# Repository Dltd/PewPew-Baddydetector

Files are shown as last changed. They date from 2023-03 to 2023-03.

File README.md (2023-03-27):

# Baddydetector
PoC for having actions of baddies in the virtual world, visible in the physical world.

v3:
The Raspberry Pi connects to a server on which multiple honeypots run.
The server listens on 8 ports and will monitor the log files of the honeypots for new attacks or automated scans and hacking attempts. 

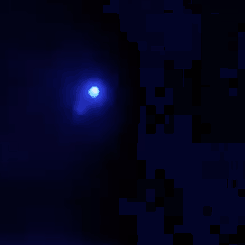
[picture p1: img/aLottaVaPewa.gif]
 

The logs are tailed and bound to one of the ports. One log is monitored twice, where the second time it is filtered on a keyword.
When the keyword is detected, it reflects input being entered in a shell on one of the honeypots. The connected LED only blinks when a bot or person actually does something in the pot.

When an activity takes place on the selected honeypots, the server will send a '1' to the client, the RPi.

When the client receives the data, it will blink two LEDs which are connected to the GPIO pin per port. 8 GPIO's are used to blink the 16 leds. 

The honeypot configuration will be deciding in if 'innocent' traffic will also be registered and blink a LED or not.
As this is not yet the final version of the idea I have, that will be for later to further tweak and tune or improve somehow.

The LEDs are put in a specific order which I liked, like so:
```bash
2	3	4	5	6	7	8
1						1
8	7	6	5	4	3	2
```

Initially I only needed to see v1 work but sometimes you just get carried away, so there you go.

For more details, consult the different versions:

[PoC_v3](/PoC_v3)

[PoC_v2](/PoC_v2)

[PoC_v1](/PoC_v1)

For the LEDs I added two test scripts to run and check if you have any dead LEDs.
You can find them [here](/Other_scripts/)

# PoC v3
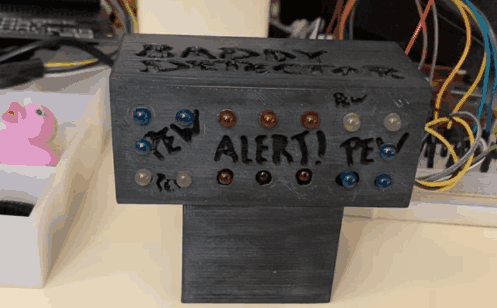
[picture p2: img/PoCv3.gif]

  
# PoC v2
name

# PoC v1
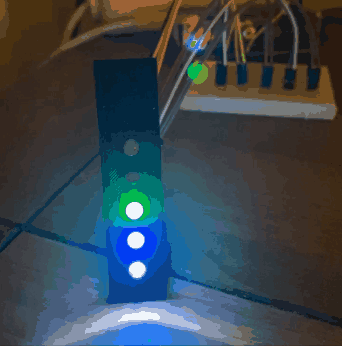
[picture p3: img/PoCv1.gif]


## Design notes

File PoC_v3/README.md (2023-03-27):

# Baddydetector
PoC for having actions of baddies in the virtual world, visible in the physical world.

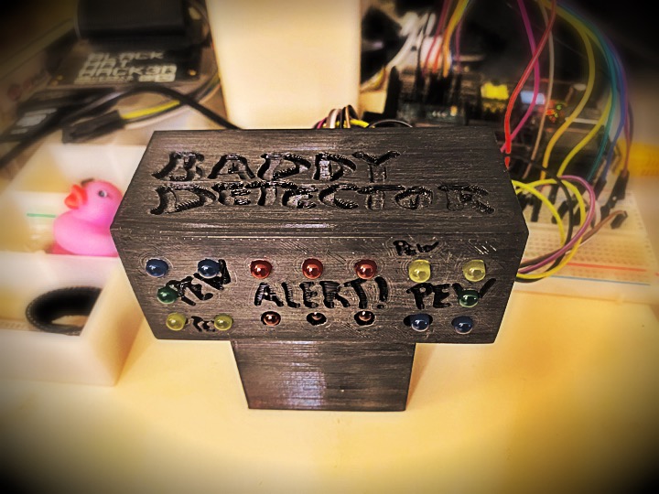
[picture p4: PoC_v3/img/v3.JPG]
Version 3


# Pics
[some of the 3D stuff](https://github.com/Dltd/PewPew-Baddydetector/blob/main/PoC_v3/README.md#3d-stuff)

[Mess is fun!](https://github.com/Dltd/PewPew-Baddydetector/blob/main/PoC_v3/README.md#some-mess)

[Soldering and wiring](https://github.com/Dltd/PewPew-Baddydetector/blob/main/PoC_v3/README.md#soldering-and-wiring)

# v3
The Raspberry Pi connects to a server on which multiple honeypots run.
The server listens on 8 ports and will monitor log files of 8 honeypots for new attacks or automated scans and hacking attempts. 

The logs are tailed and bound to one of the ports. One log is monitored twice, where the second time it is filtered on a keyword.
When the keyword is detected, it reflects input being entered in a shell on one of the honeypots. The connected LED only blinks when a bot or person actually does something in the pot.

When an activity takes place on the selected honeypots, the server will send a '1' to the client, the RPi.

When the client receives the data, it will blink two LEDs which are connected to the GPIO pin per port. 8 GPIO's are used to blink the 16 leds. 

The honeypot configuration will be decisive if 'innocent' traffic will also be registered and blink a LED or not.
As this is not yet the final version of the idea I have, that will be for later to further tweak and tune or improve somehow.

The LEDs are put in a specific order which I liked, like so:
```bash
2	3	4	5	6	7	8
1						1
8	7	6	5	4	3	2
```

Initially I only needed to see v1 work but sometimes you just get carried away, so there you go.

For more details, consult the different versions:

[PoC_v3](/PoC_v3)

[PoC_v2](/PoC_v2)

[PoC_v1](/PoC_v1)

For the LEDs I added two test scripts to run and check if you have any dead LEDs.
You can find them [here](/Other_scripts/)

# Some details of the build

The stl file used to print it [can be found here](/PoC_v3/PewPewBaddyDetectorV3.stl)

note: The LED holes might need manual adjustment to make them fit properly.
The design is for 5mm LED's.

You can edit it yourself on TinkerCAD [here](https://www.tinkercad.com/things/2NkG0boZJYC)

The server script runs on a Linux server that runs a collection of honeypots, [TPOT-CE](https://github.com/telekom-security/tpotce).
The /data directory contains the logs of the different honeypots, I selected a few popular pots to use for my idea.
These ports are only open for the IP from where the client connects from.
The idea is for a similar but larger project and it needed this PoC to get it going.

I wanted to create a physical dashboard that would notify me when there was an attack taking place on one of the honeypots.
Since this does not require a lot of power, I decided to use a Raspberry Pi 1 that I had lying around.

The RPi as a client will connect to specified ports on the server running the server script.
I designed and printed a LED holder that could stand on my desk and wired the LEDS to the RPi.

I have done some undocumented tests with a RPi Zero W but the functionality is limited due to the lack of real threading.
This can be simulated and runs sort of near real time but I haven't had time to further explore it yet.

# v3 model
https://youtu.be/B9omcdxjBJs



# PoC v3

v3BaddyDetector (https://www.youtube.com/watch?v=B9omcdxjBJsQ)

[Server](/PoC_v3/v3_pewserver.v3.1.py)

[Client](/PoC_v3/v3_pewclient.v3.py)

To make it more useful and easier to maintain, the v2 functionality was converted to python.

# PewClient and PewServer

Two Python scripts, pewclient.py and pewserver.py are designed to work together to monitor log files and visually indicate new attacks using LEDs on a Raspberry Pi.

# PewClient

The pewclient.py script runs on a Raspberry Pi 1 that I had lying around, collection dust. It is responsible for connecting to the pewserver.py script. Upon receiving signals from the server, it blinks the corresponding LED to indicate new attacks taking plsce. The script automatically reconnects to the server if the connection is lost and can be gracefully terminated by typing exit in the console. 

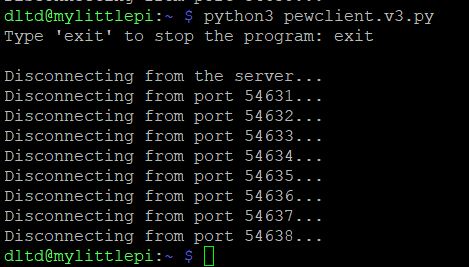
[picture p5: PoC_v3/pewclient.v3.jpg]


# PewServer

The pewserver.py script is a server that listens on multiple ports, each corresponding to a specific log file. When a client (like pewclient.py) connects to one of the ports, the server tails the associated log file in real-time. For each new line detected in the log, the server sends a signal to the connected client.

For one log, the data is filtered to reflect current activitiy by a bot or baddie in a shell in one of the honeypots.

When the client disconnects, the server gracefully handles the disconnection and continues listening for new connections.

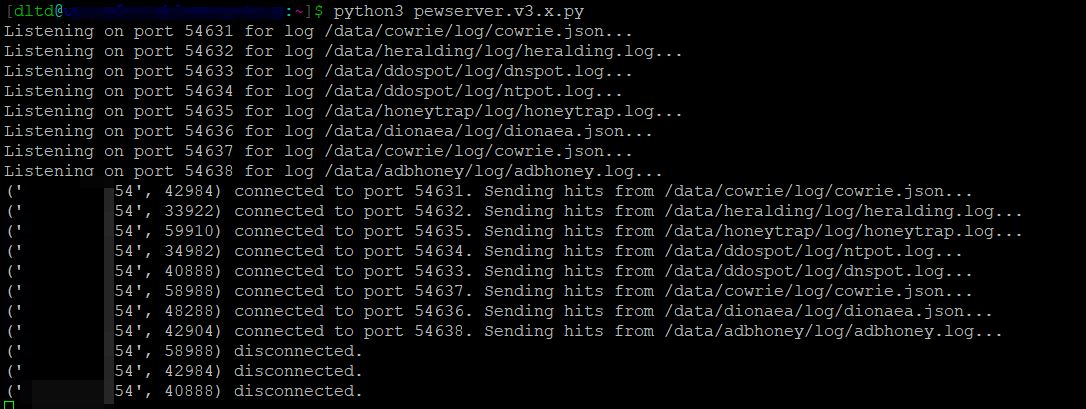
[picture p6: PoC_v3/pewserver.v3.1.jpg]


# Setup

Clone the repository:
```bash
git clone https://github.com/Dltd/PewPew-Baddydetector.git
```

Update the IP address and port numbers in both pewclient.py and pewserver.py to match your configuration.

Make sure the required dependencies are installed on the RPi and the server running the server script:

RPi:
```bash
pip install gpiozero aioconsole asyncio
```
Server:
```bash
pip install asyncio aiofiles
```

# Running the PoC

Run the pewserver.py script on the machine where the log files are located:
```bash
python3 pewserver.py
```

Run the pewclient.py script on the Raspberry Pi connected to the LEDs:
```bash
python3 pewclient.py
```

# Usage
When the pewclient.py script is running and connected to the pewserver.py script, it will blink the LEDs according to the incoming signals from the server. Each LED corresponds to a specific log file, and blinks whenever there is a new entry in that log file.

To gracefully stop the pewclient.py script, type exit in the console.

The LEDs are wired in pairs, in my PoC I used this configuration to make it more fun.

```
2	3	4	5	6	7	8

1						1

8	7	6	5	4	3	2
```

#  3D stuff

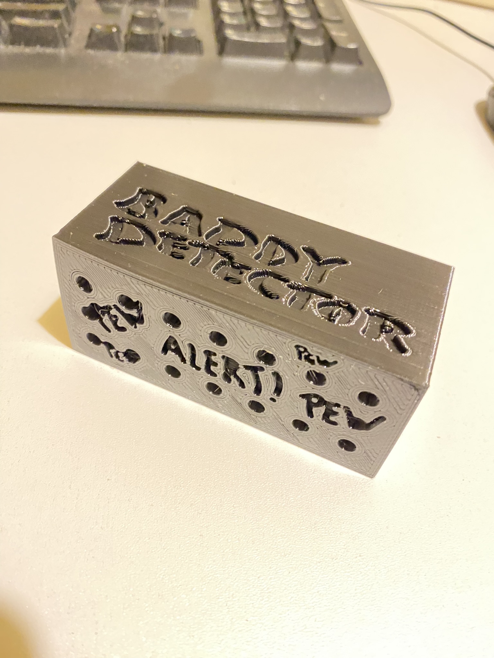
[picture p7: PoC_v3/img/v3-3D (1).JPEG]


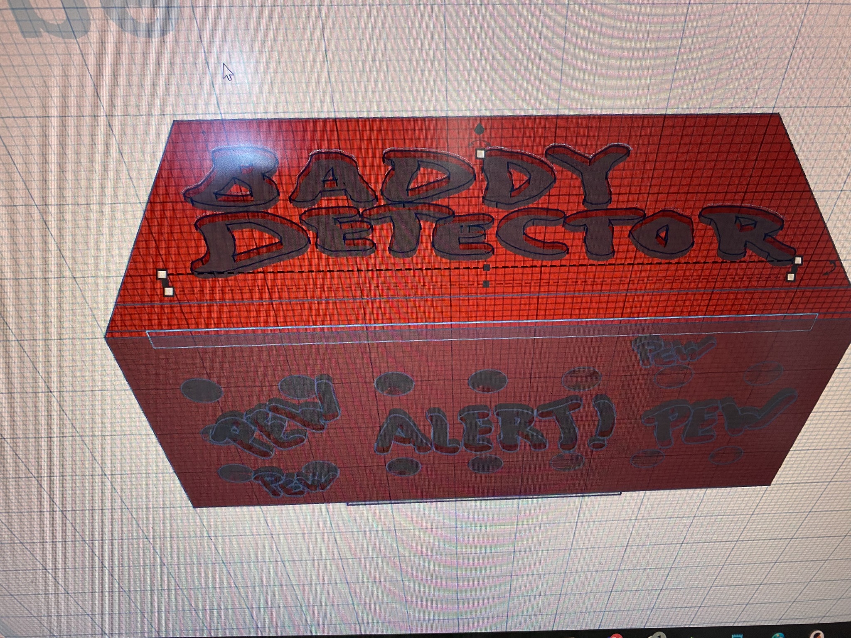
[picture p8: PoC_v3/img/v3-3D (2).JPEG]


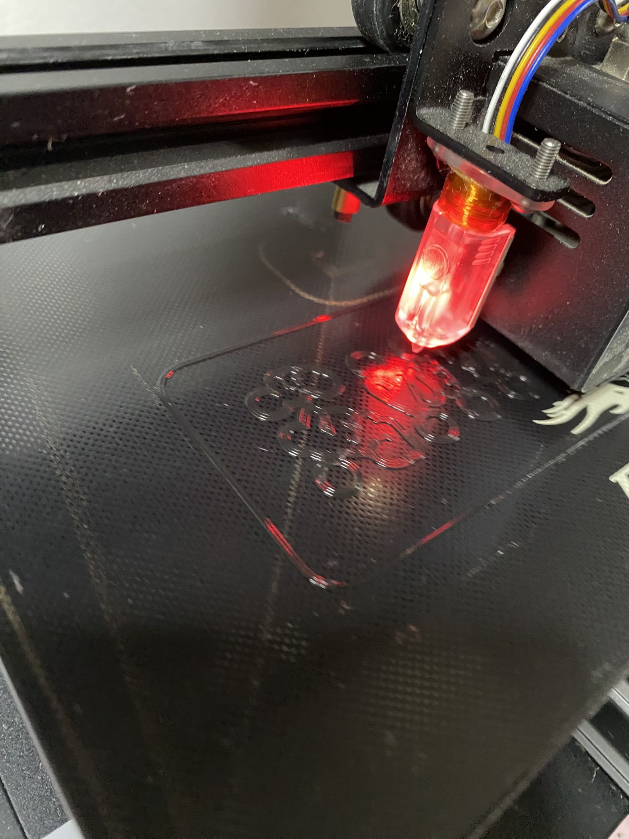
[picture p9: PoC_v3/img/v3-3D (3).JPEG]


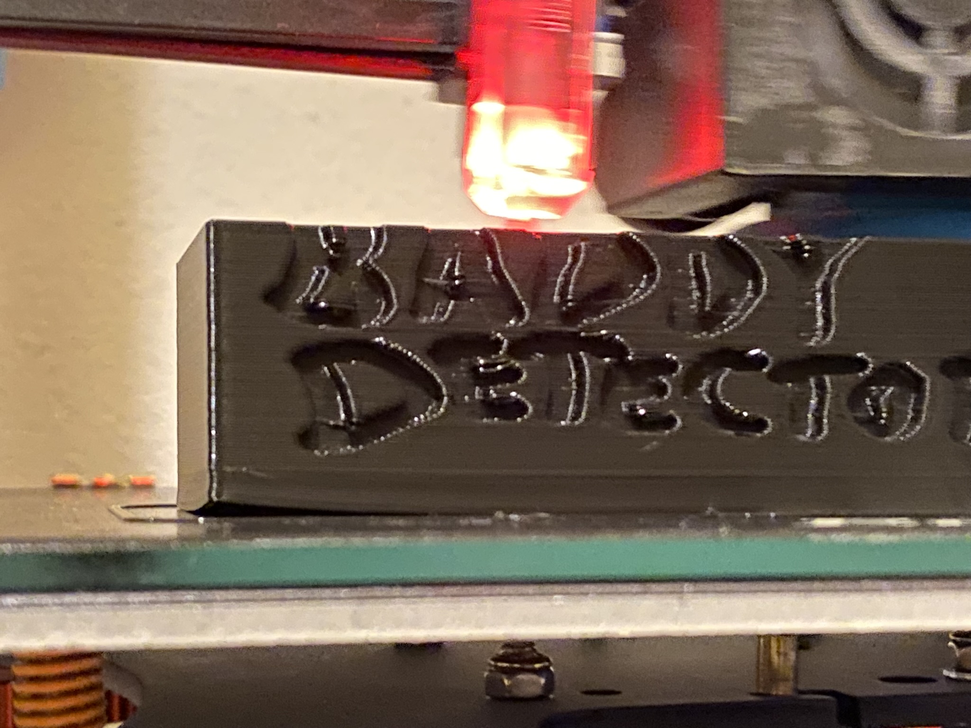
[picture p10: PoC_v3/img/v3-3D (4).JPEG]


# Some mess
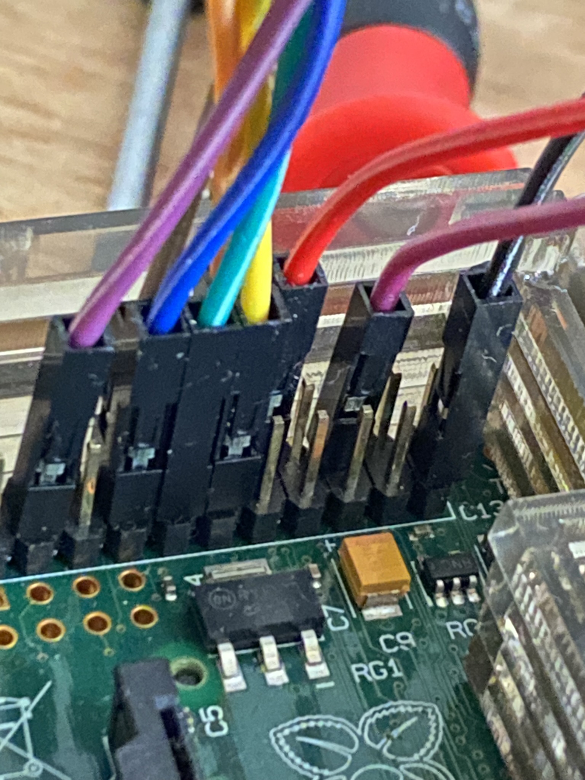
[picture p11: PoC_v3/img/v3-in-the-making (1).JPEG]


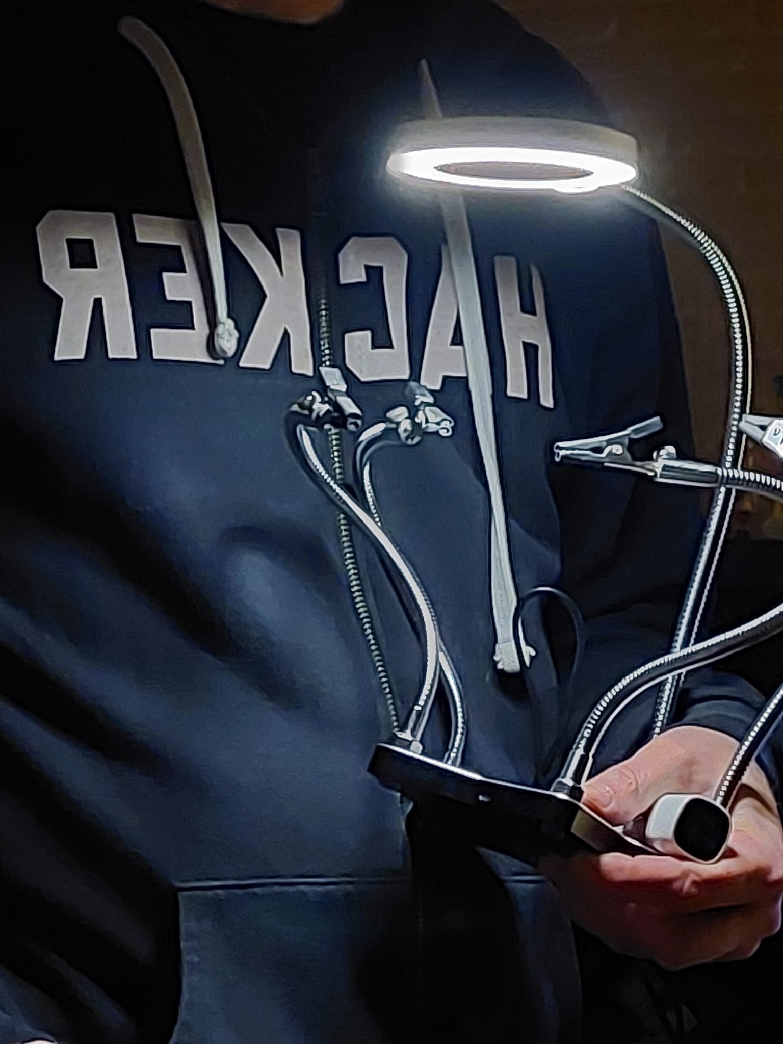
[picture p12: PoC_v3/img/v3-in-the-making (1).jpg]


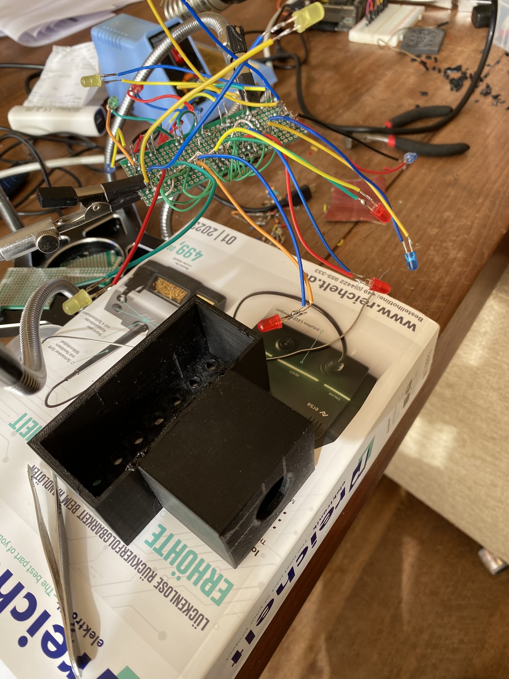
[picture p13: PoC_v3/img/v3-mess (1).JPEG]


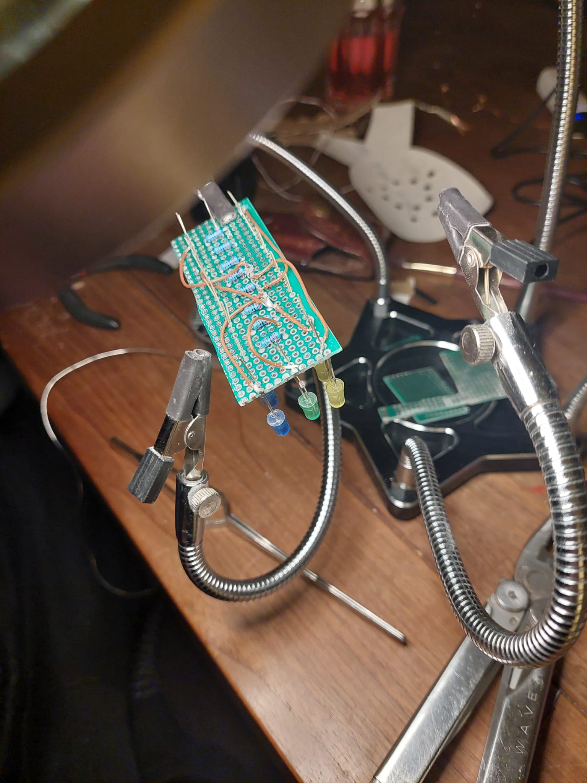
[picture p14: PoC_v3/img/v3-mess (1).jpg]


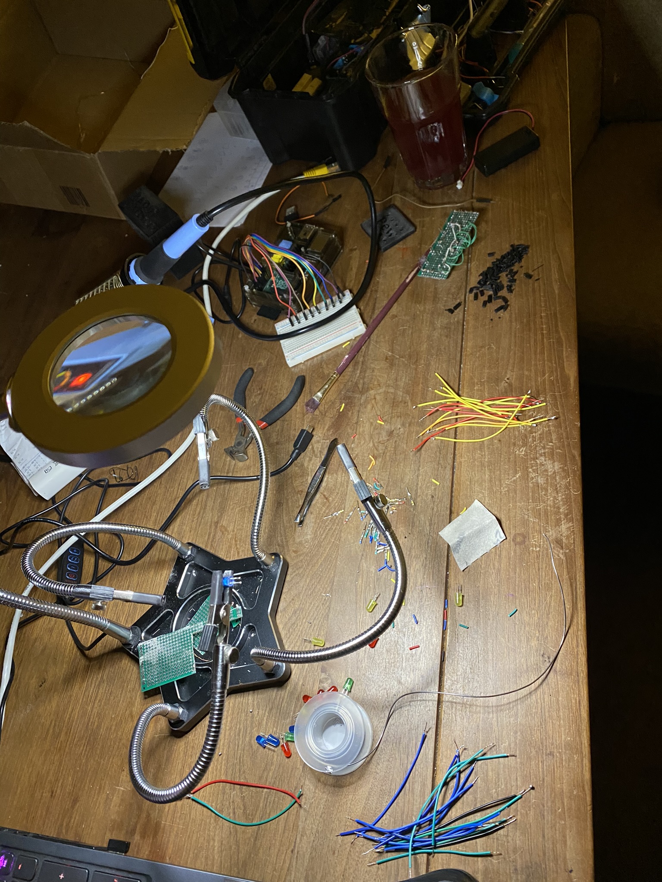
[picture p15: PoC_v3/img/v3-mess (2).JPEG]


# Soldering and wiring

Initially I had the LEDs soldered to a prototyping board.

The print I made and the base holding the print required some tweaking and tuning but since it was "just" for a PoC I didn't give it the extra bit of TLC it needed to make it fit properly. Also, the board was just a little too big to have space left to get the leds into the holes. 

So, I used a soldering iron to melt away some of the excess filament of the "neck" of the base but that did not improve that challenge all that much. ALso the center bottom three leds cannot be pushed in deep enough.

After soldering them all on the board, I cut them loose again and soldered wires on to the leds to have a little bit more freedom of movement within the casing.

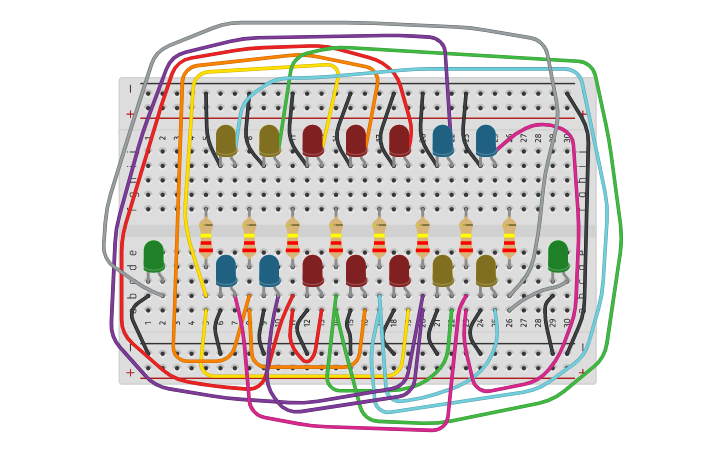
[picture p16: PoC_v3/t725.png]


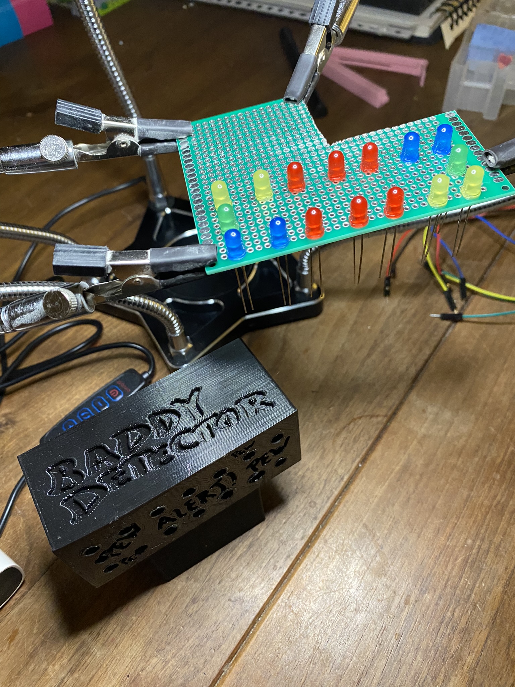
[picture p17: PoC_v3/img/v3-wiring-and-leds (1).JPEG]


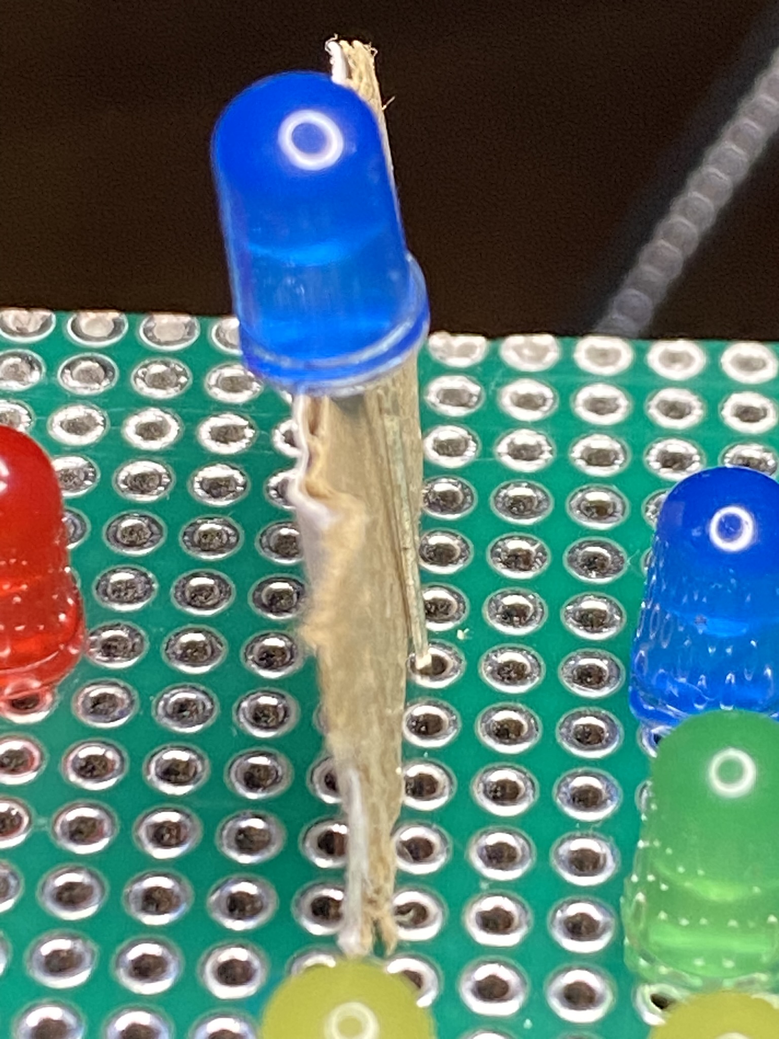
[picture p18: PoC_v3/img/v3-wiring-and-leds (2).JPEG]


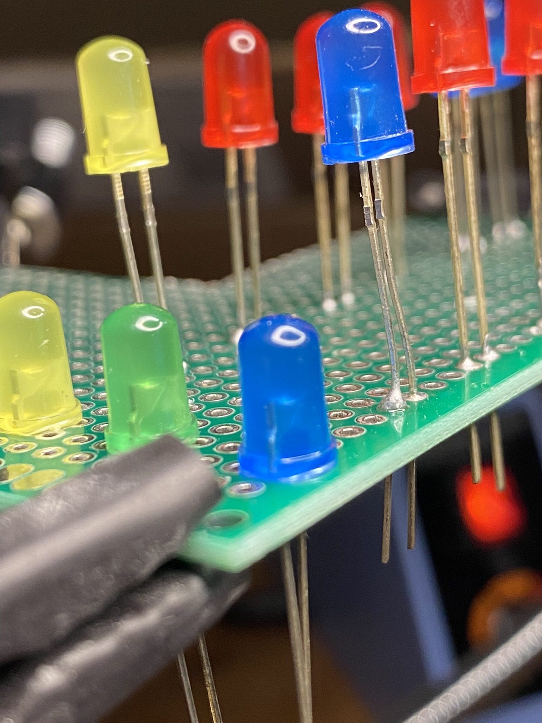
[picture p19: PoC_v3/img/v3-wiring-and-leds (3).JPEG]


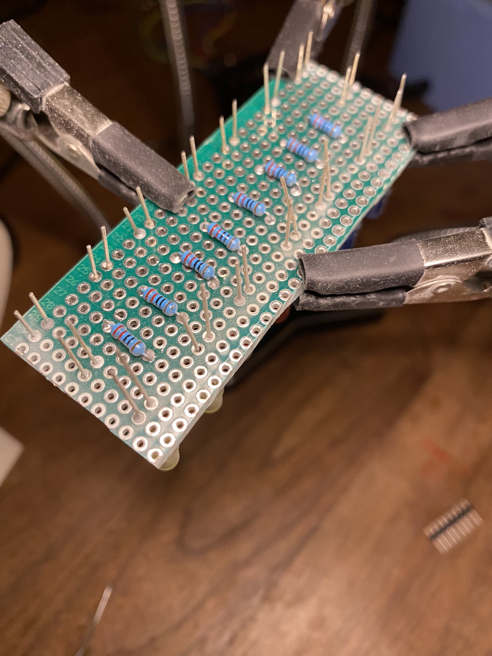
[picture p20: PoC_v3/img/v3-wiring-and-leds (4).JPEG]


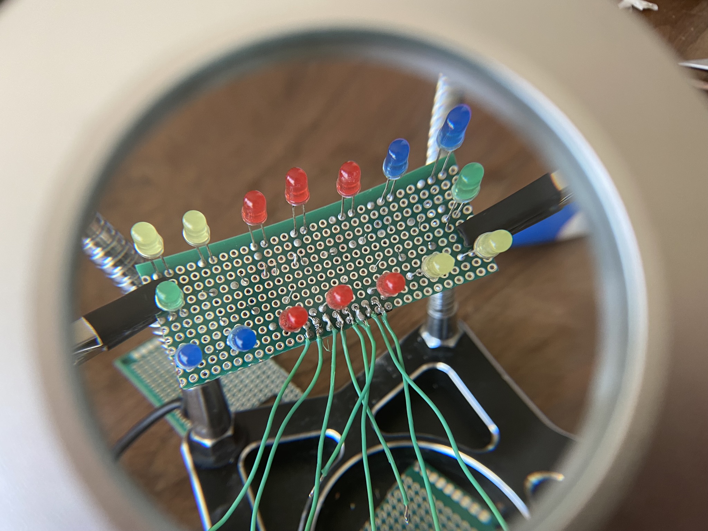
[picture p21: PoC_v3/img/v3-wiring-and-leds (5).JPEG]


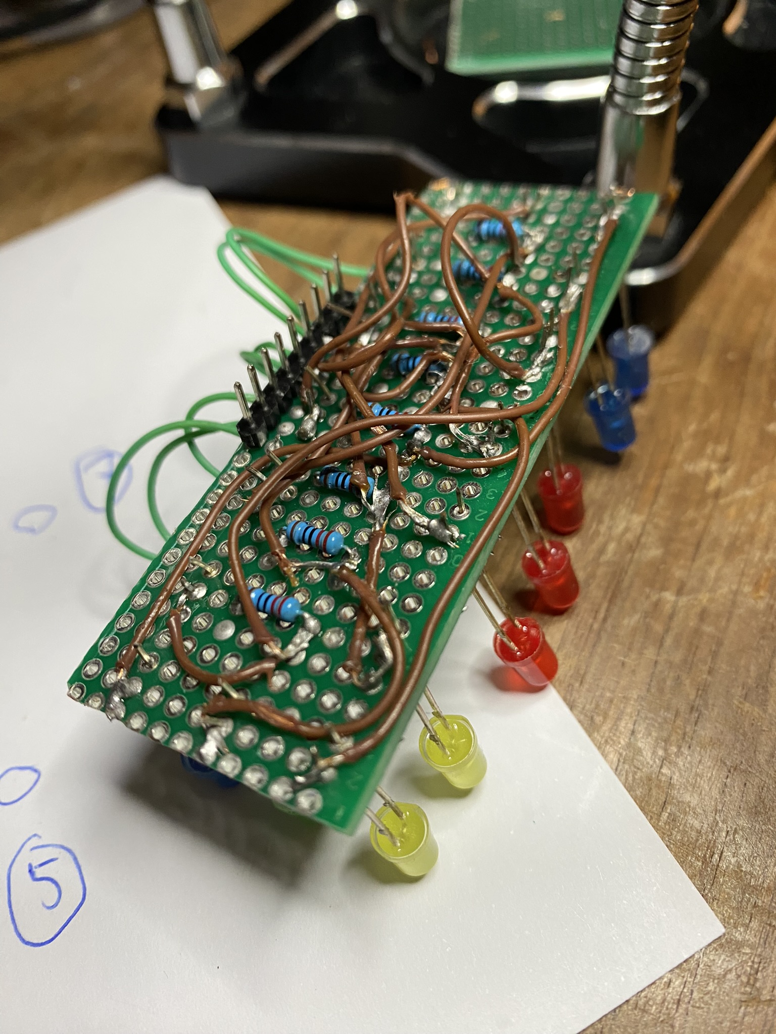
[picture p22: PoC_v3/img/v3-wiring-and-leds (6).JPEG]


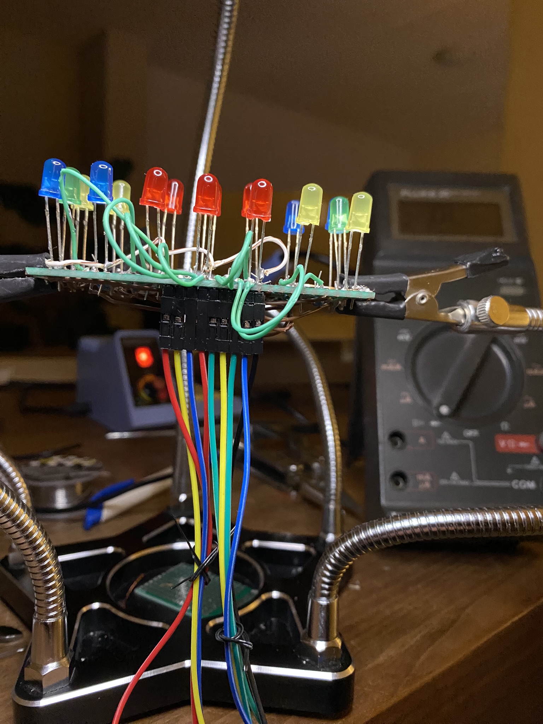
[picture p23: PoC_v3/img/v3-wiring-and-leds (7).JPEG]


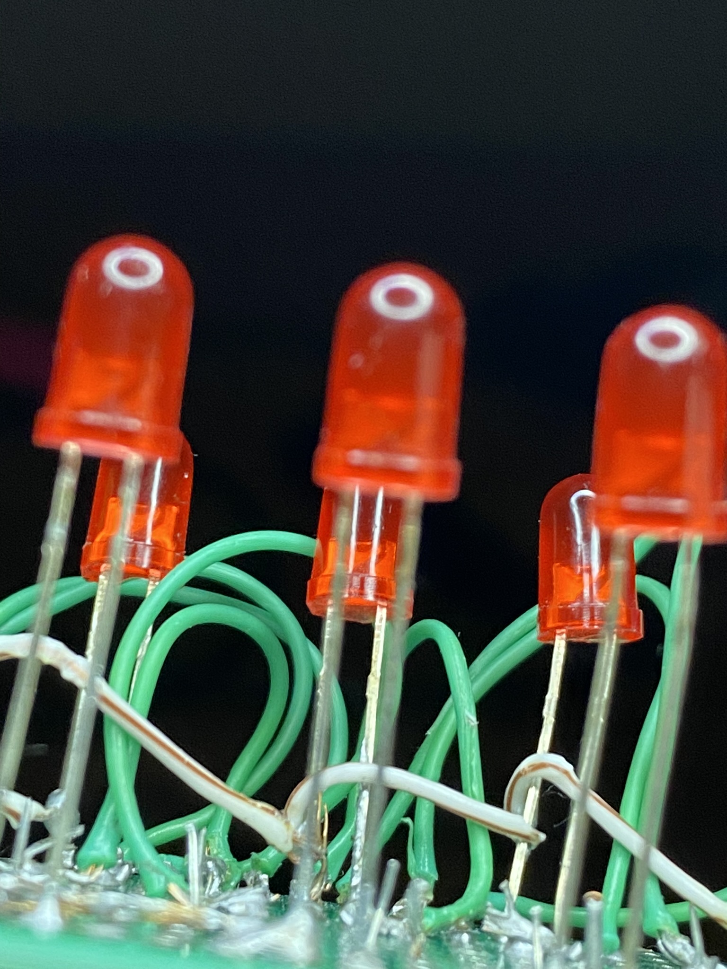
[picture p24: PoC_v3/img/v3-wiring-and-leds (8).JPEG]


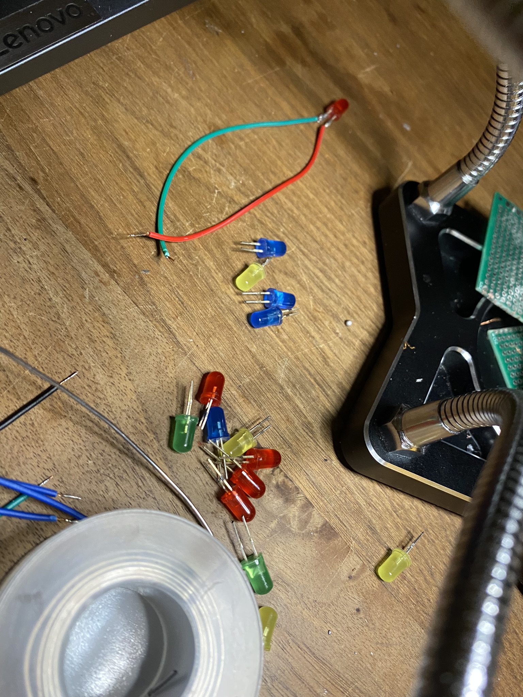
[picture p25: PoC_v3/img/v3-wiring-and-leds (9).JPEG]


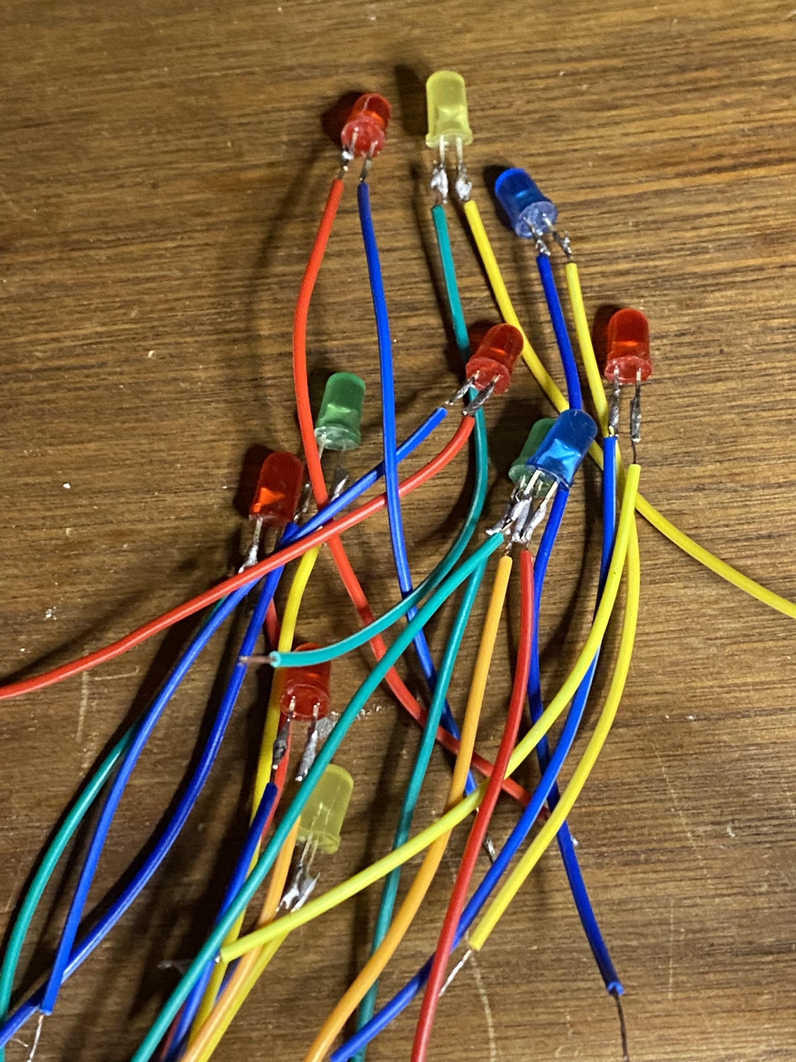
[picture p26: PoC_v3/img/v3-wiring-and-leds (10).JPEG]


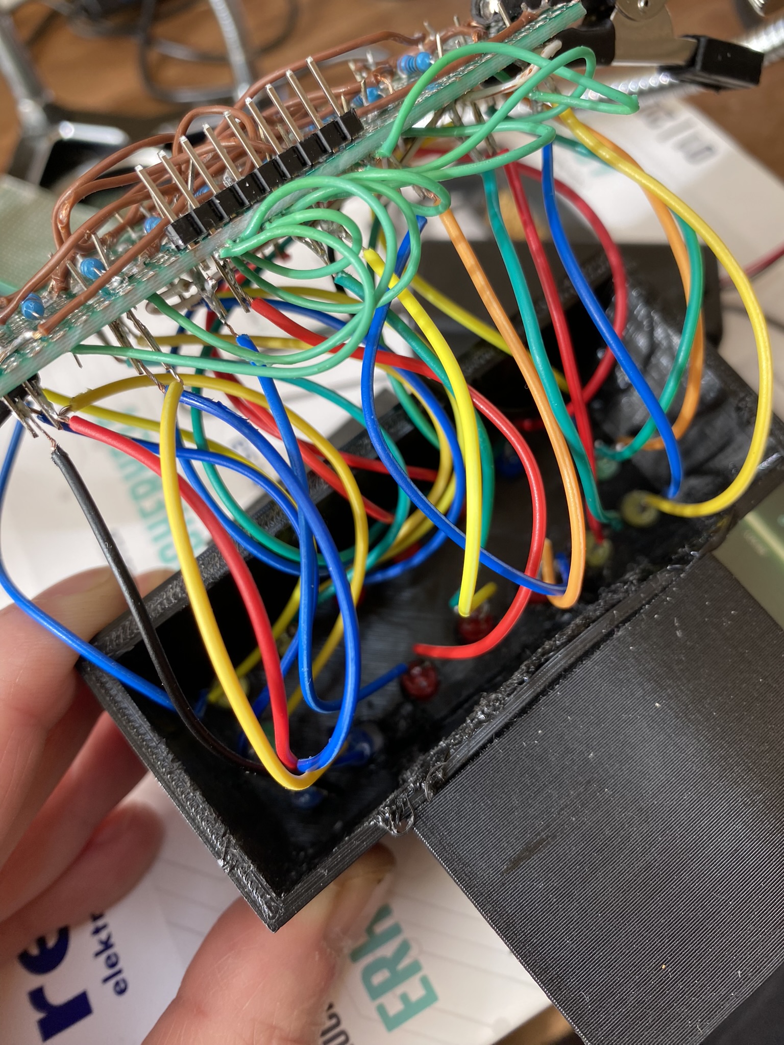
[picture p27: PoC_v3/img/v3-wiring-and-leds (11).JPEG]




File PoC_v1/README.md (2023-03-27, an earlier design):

# Some details of the build

The stl file used to print the LED stand [can be found here](/PoC_v1/PewPewBaddyDetectorV1.stl).
It was not made with beauty in mind, so the quality might not be all too good ;)

The TinkerCAD 3D file can be found [here](https://www.tinkercad.com/things/1tUUNth2Pv8).

# v1 model
https://youtube.com/shorts/qewCp_70Njc



# POC v1


Using a really simple setup with nc, tail and tmux was the quickest way to test my initial idea which works fine for the PoC.

The server script runs on a Linux server that runs a collection of honeypots, [T-Sec's TPOTCE](https://github.com/telekom-security/tpotce).

The /data directory contains the logs of the different honeypots, I selected a few popular pots to use for my idea.
The idea is for a similar but larger project and needed this PoC to get it going.

I wanted to create a physical dashboard that would notify me when there was an attack taking place on one of the honeypots.
Since this does not require a lot of power, I decided to use a Raspberry Pi 1 that I had lying around.

The RPi as a client will connect to specified ports on the server, where the server script runs.
I designed and printed a small LED holder that could stand on my desk and wired the LEDS to the RPi.

The server script will create 5 panes and run the relevant commands:

[v1_pewpewserver.sh](/PoC_v1/v1_pewpewserver.sh)

The client script will create 5 panes and run a python script that blinks a LED when an new entry arrives in the honeypot logs:

[v1_pewpewclient.sh](/PoC_v1/v1_pewpewclient.sh)

The pyton script "client_led{num}.py" is used to blink 1 LED, multiple scripts are used in this test: 

[v1_client_led1.py](/PoC_v1/v1_client_led1.py)

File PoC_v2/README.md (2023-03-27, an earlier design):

# Some details of the build

The stl file used to print the cover [can be found here](/PoC_v2/PewPewBaddyDetectorV2cover.stl)
and the base [here](/PoC_v2/PewPewBaddyDetectorV2base.stl)

The TinkerCAD 3D files can be found [here](https://www.tinkercad.com/things/a0UG9sc6krN).
and the base [is this one](https://www.tinkercad.com/things/4kdzSC4dGDb).

The server script runs on a Linux server that runs a collection of honeypots, [TPOT-CE](https://github.com/telekom-security/tpotce).
The /data directory contains the logs of the different honeypots, I selected a few popular pots to use for my idea.
The idea is for a similar but larger project and it needed this PoC to get it going.

I wanted to create a physical dashboard that would notify me when there was an attack taking place on one of the honeypots.
Since this does not require a lot of power, I decided to use a Raspberry Pi 1 that I had lying around.

The RPi as a client will connect to specified ports on the server, where the server script runs.
I designed and printed a LED holder that could stand on my desk and wired the LEDS to the RPi.

# v2 model
https://www.youtube.com/shorts/phfXufrK0ew

# Pewpew
https://youtube.com/shorts/jz_PYNGq8H0

This version works similar as v1 with bash scripts using tmux and a python script per GPIO/LED, it has a few more LEDs and a different casing.

# PoC v2



[Server](/PoC_v2/v2_pewpewserver.sh)

[Client](/PoC_v2/v2_pewpewclient.sh)

[LED](/PoC_v2/v2_attackled.py)

v2 of this Proof of Concept (PoC) script  utilizes Tmux to create a new session and run multiple Python scripts concurrently in separate panes. Each script represents an individual LED on the pewclient, which blinks according to the incoming signals.

Two scripts, pewpewclient.sh and pewpewserver.sh, work together to monitor log file activity and visually indicate an attack taking place on the honeypot.
The heavily rely on ``tmux`` which is a requirement to run the scripts.

Usage
The client script creates a new Tmux session named "pewpew" and splits it into multiple panes. In each pane, it runs one of the Python scripts (attack_led1.py to attack_led8.py). These scripts control the LEDs on the pewclient, with each LED corresponding to a specific log file.

The server script creates a new Tmux session named "pewpew" and splits it into multiple panes. In each pane, it simply runs a command in each pane, similar to this:
```bash
tail -f /data/cowrie/log/cowrie.json | nc -nvklp 54631
```

A total of 8 ports will be listening and when the client connects, it will stream the data of 8 different logs to the client.
Each new entry in the log files will trigger the client script to execute the attack_led.py script to blink the appropriate led.

To connect to the Tmux session after running the script, use the following command:

```bash
tmux attach -t pewpew
```
The Tmux session helps you monitor the blinking pattern of the LEDs, allowing you to efficiently keep track of your logs in real-time.

# Some images





# Assembly

















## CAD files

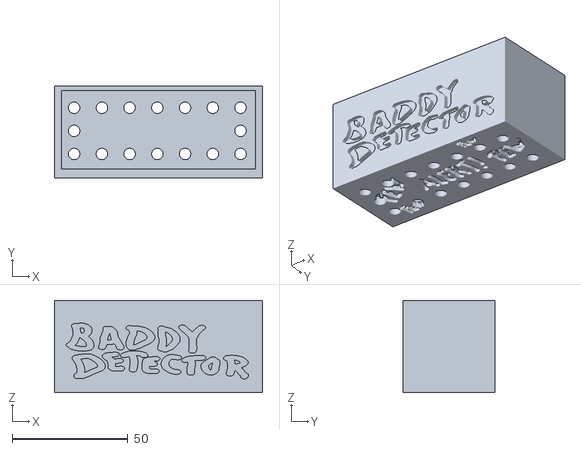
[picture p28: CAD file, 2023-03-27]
PoC_v3/PewPewBaddyDetectorV3.stl
90.0 x 40.0 x 40.0

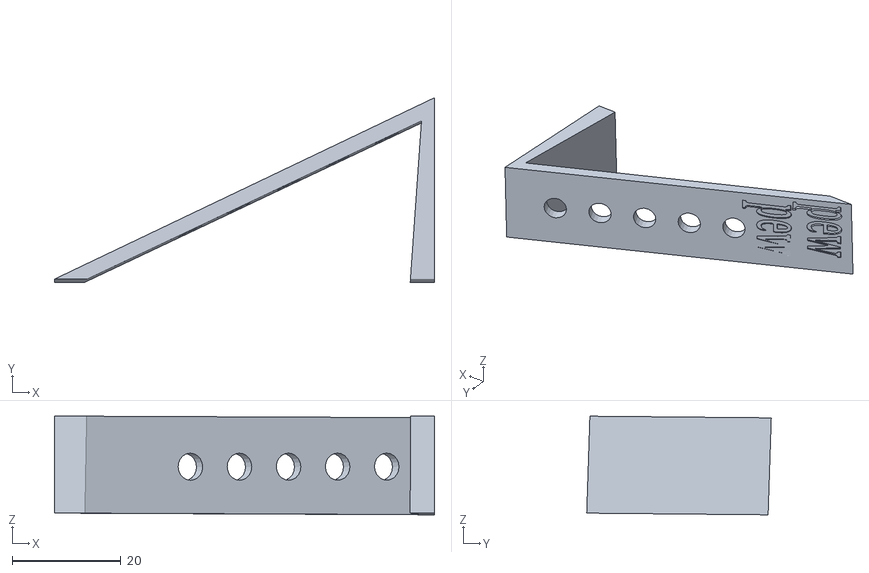
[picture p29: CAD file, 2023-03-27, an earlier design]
PoC_v1/PewPewBaddyDetectorV1.stl
70.0 x 34.0 x 18.2

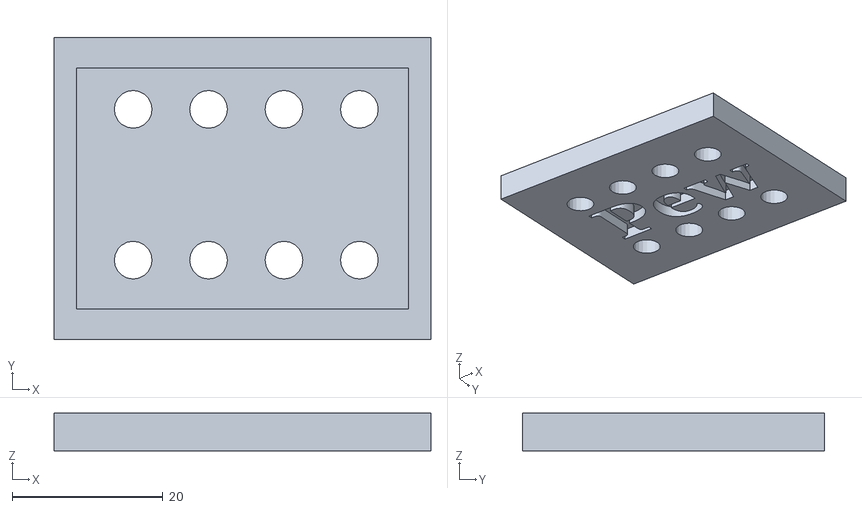
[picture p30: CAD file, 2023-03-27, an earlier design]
PoC_v2/PewPewBaddyDetectorV2cover.stl
50.0 x 40.0 x 5.00

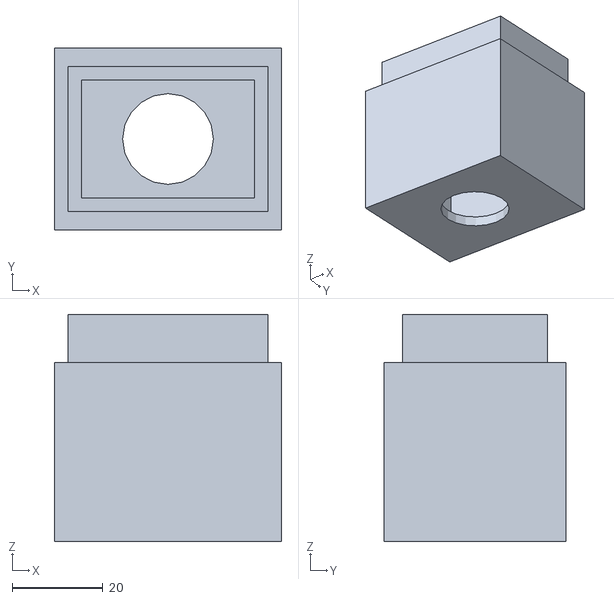
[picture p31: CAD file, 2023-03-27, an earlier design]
PoC_v2/PewPewBaddyDetectorV2base.stl
50.0 x 40.0 x 50.0

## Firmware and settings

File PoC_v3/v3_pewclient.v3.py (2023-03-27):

#!/usr/bin/python
# BaddyDetector v0.69
# -----------------------
# pewclient.{version}.py PoC
# .__ . ,   .
# |  \|-+- _|
# |__/| | (_]
#
# Version: v3
# -----------------------
# This PoC consists of a server and client script, the server listens to multiple ports,
# and the client connects to these ports. Log files are 'tailed' and will have the client
# blink a corresponding LED when the new entries arrive.
#
# The pewclient.py script starts by executing an LED pattern ( pewpew_engage() )
# The startup pattern can assist in finding a dead LED and also just looks fun to have as start indicator.
# ------------
# It is a Python client that connects to a remote server to receive log updates.
# It establishes multiple connections to the server on specified ports and listens for updates.
# ------------
# When data is received, the script toggles corresponding LEDs to indicate activity.
# The server script is pewserver.{version}.py.
# ------------
# You have to update the SERVER_IP to match the server you connect to.
# ------------
# This PoC was built on a Raspberry Pi 1
# and uses GPIO pins 4, 17, 18, 22, 23, 24, 25 and 27 to control the LEDs.
# -----------------------
#

# Import required libraries and set up global variables
import asyncio  # Import the asyncio library for creating asynchronous tasks
import aioconsole  # Import the aioconsole library for reading user input asynchronously
from gpiozero import LED  # Import the LED class from the gpiozero library for controlling LEDs
from asyncio import StreamReader, StreamWriter  # Import the StreamReader and StreamWriter classes for communicating with the server
import time  # Import the time library for adding delays in the code
import RPi.GPIO as GPIO  # Import the RPi.GPIO library for controlling the Raspberry Pi's GPIO pins

SERVER_IP = "YOUR_SERVER_IP_HERE"  # Set the IP address of the server
START_PORT = 54631  # Set the starting port number for the program
NUM_PORTS = 8  # Set the number of ports to be used in the program
GPIO_PINS = [4, 17, 18, 22, 23, 24, 25, 27]  # Define a list of GPIO pins to be used for the LEDs
leds = [LED(pin) for pin in GPIO_PINS]  # Create a list of LED objects to be used in the program

# Define a function that moves the LEDs back and forth and blinks them in a specific pattern
def pewpew_engage():
    # Set up the GPIO pins
    pins = [4, 17, 18, 22, 23, 24, 25, 27]
    GPIO.setmode(GPIO.BCM)
    for pin in pins:
        GPIO.setup(pin, GPIO.OUT)

    # Move LEDs back and forth twice
    for j in range(2):
        for i in range(8):
            GPIO.output(pins[i], GPIO.HIGH)
            time.sleep(0.07)
            GPIO.output(pins[i], GPIO.LOW)
        for i in range(6, 0, -1):
            GPIO.output(pins[i], GPIO.HIGH)
            time.sleep(0.07)
            GPIO.output(pins[i], GPIO.LOW)

    # Turn all LEDs off
    for i in range(8):
        GPIO.output(pins[i], GPIO.LOW)

    # Blink LEDs 4 and 6
    for i in range(2):
        GPIO.output(pins[3], GPIO.HIGH)
        time.sleep(0.1)
        GPIO.output(pins[3], GPIO.LOW)
        GPIO.output(pins[5], GPIO.HIGH)
        time.sleep(0.1)
        GPIO.output(pins[5], GPIO.LOW)

    # Very shortly blink all LEDs
    for i in range(2):
        for i in range(8):
            GPIO.output(pins[i], GPIO.HIGH)
        time.sleep(0.05)
        for i in range(8):
            GPIO.output(pins[i], GPIO.LOW)


# Execute the function that moves the LEDs
pewpew_engage()

# Define an asynchronous function that connects to the server and reads data from the specified port.
# Asynchronous tasks in the asyncio module allow for concurrent execution of multiple tasks without
# blocking the main thread. The module uses an event loop to manage the execution of these tasks, 
# allowing them to run concurrently and switch between each other when waiting for input/output or sleeping.
async def handle_port(port: int, led: LED):
    async def blink_led():
        led.blink(on_time=0.05, off_time=0.05, n=1)
        await asyncio.sleep(0.2)

    while True:
        try:
            reader, writer = await asyncio.open_connection(SERVER_IP, port)
            while True:
                data = await reader.read(1)
                if data:
                    await blink_led()
                else:
                    data == b'0'
        except ConnectionError:
            print(f"Connection to port {port} failed. Retrying in 5 seconds...")
            await asyncio.sleep(5)
        except asyncio.CancelledError:
            print(f"Disconnecting from port {port}...")
            writer.close()
            await writer.wait_closed()
            break

# Define an asynchronous function that reads user input and stops the program when the user types "exit"
async def user_input():
    while True:
        user_command = await aioconsole.ainput("Type 'exit' to stop the program: ")
        if user_command.lower() == "exit":
            return

# Define the main function that creates tasks for each port and user input, and runs the tasks
async def main():
    tasks = [asyncio.create_task(handle_port(START_PORT + i, leds[i])) for i in range(NUM_PORTS)]
    input_task = asyncio.create_task(user_input())

    try:
        await input_task
    except KeyboardInterrupt:
        pass
    finally:
        print("\nDisconnecting from the server...")
        for task in tasks:
            task.cancel()
            await task

# Execute the main function
if __name__ == "__main__":
    asyncio.run(main())  # Run the main function using asyncio's run() function

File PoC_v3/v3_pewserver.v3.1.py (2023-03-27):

#!/usr/bin/python
# BaddyDetector v0.69
# -----------------------
# pewserver.{version}.py PoC
# .__ . ,   .
# |  \|-+- _|
# |__/| | (_]
#
# Version: v3.1
# -----------------------
# This PoC consists of a server and client script, the server listens to multiple ports,
# and the client connects to these ports. Log files are 'tailed' and will have the client
# blink a corresponding LED when the new entries arrive.
#
# The pewserver.py script listens on multiple ports, each corresponding to a specific log file.
# -----------
# When a client connects to any or all of the ports, the server tails the associated log file in real-time.
# The client script is pewclient.py.
# ------------
# For each new line detected in the log, the server sends a signal to the connected client.
# The cowrie logfile for port 54637 will only send a signal when input in the honeypot is entered.
#
# When the client disconnects, the server gracefully handles the disconnection and continues listening for new connections.
# -----------------------
#
#

# Asynchronous tasks in the asyncio module allow for concurrent execution of multiple tasks without
# blocking the main thread. The module uses an event loop to manage the execution of these tasks,
# allowing them to run concurrently and switch between each other when waiting for input/output or sleeping.

import asyncio  # Import the asyncio library for creating asynchronous tasks
import aiofiles  # Import the aiofiles library for asynchronous file I/O
from asyncio import StreamReader, StreamWriter  # Import the StreamReader and StreamWriter classes for communicating with the client

# Dictionary mapping ports to log files
LOG_FILES = {
    54631: "/data/cowrie/log/cowrie.json",
    54632: "/data/heralding/log/heralding.log",
    54633: "/data/ddospot/log/dnspot.log",
    54634: "/data/ddospot/log/ntpot.log",
    54635: "/data/honeytrap/log/honeytrap.log",
    54636: "/data/dionaea/log/dionaea.json",
    54637: "/data/cowrie/log/cowrie.json",
    54638: "/data/adbhoney/log/adbhoney.log",
    # Add more log files if needed
}

# Coroutine to tail log file and send updates to the connected client
#
# the data for port 54637 will only be used as a trigger for the client
# if there is input typed in the honeypot
async def tail_log_file(log_file, writer):
    """
    Tails a log file and sends updates to the connected client if the log entry contains "cowrie.command.input".

    Parameters:
    log_file (str): Path to the log file.
    writer (StreamWriter): StreamWriter object for communicating with the client.
    """
    async with aiofiles.open(log_file, "r") as f:
        await f.seek(0, 2)  # Move to the end of the file
        while not writer.is_closing():
            line = await f.readline()
            if line and "cowrie.command.input" in line and "54637" in log_file:
                try:
                    writer.write(b"1")  # Send the single character '1'
                    await writer.drain()
                except (ConnectionResetError, BrokenPipeError):
                    break
            elif line and "54637" not in log_file:
                try:
                    writer.write(b"1")  # Send the single character '1'
                    await writer.drain()
                except (ConnectionResetError, BrokenPipeError):
                    break
            else:
                await asyncio.sleep(0.1)  # Wait for a short period before checking again

# Coroutine to handle a new client connection
async def handle_connection(reader: StreamReader, writer: StreamWriter):
    """
    Coroutine to handle a new client connection. Sends log updates to the client for the corresponding port.

    Parameters:
    reader (StreamReader): StreamReader object for reading data from the client.
    writer (StreamWriter): StreamWriter object for writing data to the client.
    """
    addr = writer.get_extra_info("peername")
    port = writer.get_extra_info("sockname")[1]

    log_file = LOG_FILES.get(port)
#   if the log file is cowrie.json and the connected port is 54637
#
    if log_file and port == 54637 and "cowrie.json" in log_file:
        print(f"{addr} connected to port {port}. Sending hits from {log_file}...")
        try:
            await tail_log_file(log_file, writer)
        except ConnectionResetError:
            print(f"Connection lost: {addr}")
        except BrokenPipeError:
            print(f"Broken pipe error: {addr}")
    elif log_file:
        print(f"{addr} connected to port {port}. Sending hits from {log_file}...")
        try:
            await tail_log_file(log_file, writer)
        except ConnectionResetError:
            print(f"Connection lost: {addr}")
        except BrokenPipeError:
            print(f"Broken pipe error: {addr}")
    else:
        print(f"{addr} connected to unknown port {port}.")
        writer.write(b"Invalid port.\n")
        await writer.drain()

    print(f"{addr} disconnected.")
    writer.close()
    try:
        await writer.wait_closed()
    except (ConnectionResetError, BrokenPipeError):
        pass

# Main coroutine to start the server
async def main():
    """
    Main coroutine to start the server. Creates a server object for each port and starts serving clients.
    """
    server_tasks = []
    for port, log_file in LOG_FILES.items():
        server = await asyncio.start_server(handle_connection, "0.0.0.0", port)
        server_tasks.append(server)
        print(f"Listening on port {port} for log {log_file}...")

    await asyncio.gather(*(s.serve_forever() for s in server_tasks))

if __name__ == "__main__":
    try:
        asyncio.run(main())  # Run the main coroutine
    except KeyboardInterrupt:
        print("\nShutting down the server gracefully...")

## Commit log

2023-03-27 Added files via upload
    Pew Pew
    [PewPewBaddyDetectorV1.stl, PewPewBaddyDetectorV2base.stl, PewPewBaddyDetectorV2cover.stl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]
2023-03-28 another LED test - with more options
